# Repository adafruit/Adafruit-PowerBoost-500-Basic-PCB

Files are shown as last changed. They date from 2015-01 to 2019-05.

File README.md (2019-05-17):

## Adafruit PowerBoost 500 Basic PCB
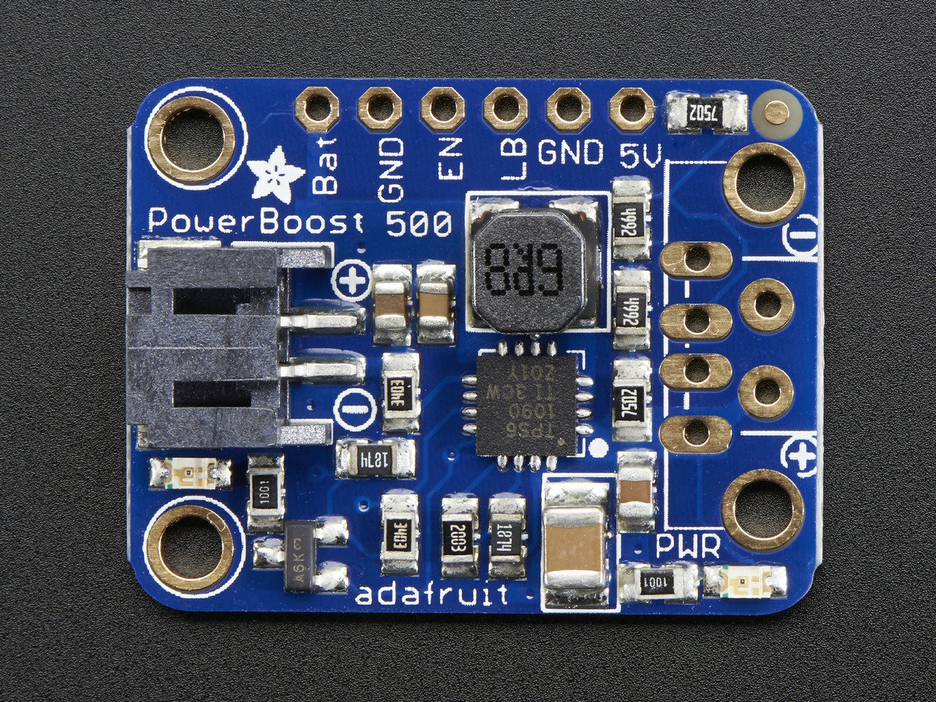
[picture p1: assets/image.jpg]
<a href="http://www.adafruit.com/products/1903"><br/>
Click here to purchase one from the Adafruit shop</a>

This little DC/DC boost converter module can run from 1.8V batteries or higher, and convert that voltage to 5.2V DC for running your 5V projects. Like our popular 5V 1A USB wall adapter, we tweaked the output to be 5.2V instead of a straight-up 5.0V so that there's a little bit of 'headroom' long cables, high draw, the addition of a diode on the output if you wish, etc. The 5.2V is safe for all 5V-powered electronics like Adafruit Metro/Trinket/Gemma/ItsyBitsy, Arduino, Raspberry Pi, or BeagleBone while preventing icky brown-outs during high current draw because of USB cable resistance.

The PowerBoost 500 has at the heart a TPS61090 boost converter from TI. This boost converter chip has some really nice extras such as low battery detection, 2A internal switch, synchronous conversion, excellent efficiency, and 700KHz high-frequency operation.

These are the Eagle CAD files for the Adafruit Adafruit PowerBoost 500 Basic breakout:
----> https://www.adafruit.com/product/1903

### License

Adafruit invests time and resources providing this open source design, please support Adafruit and open-source hardware by purchasing products from [Adafruit](https://www.adafruit.com)!

All text above must be included in any redistribution

Designed by Limor Fried/Ladyada for Adafruit Industries.
Creative Commons Attribution/Share-Alike, all text above must be included in any redistribution. 
See license.txt for additional information.

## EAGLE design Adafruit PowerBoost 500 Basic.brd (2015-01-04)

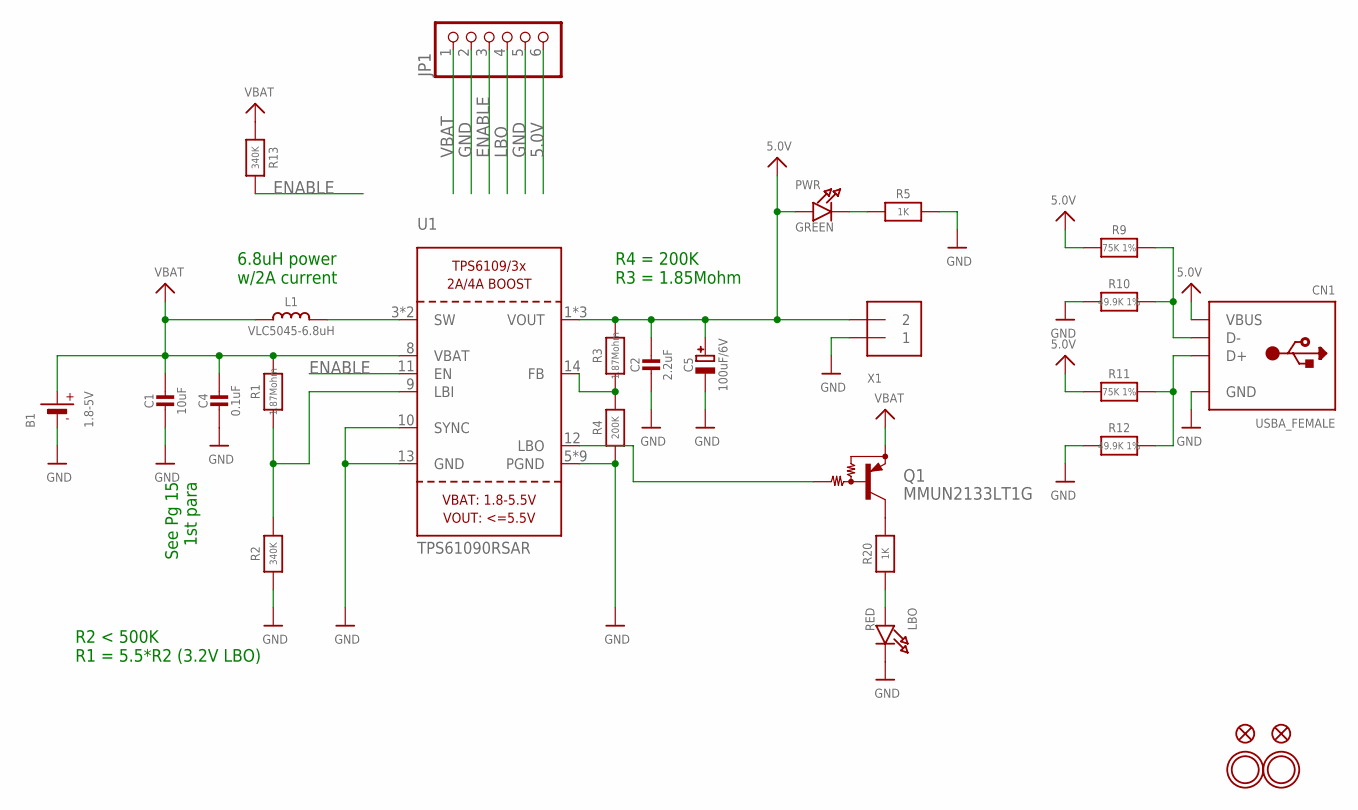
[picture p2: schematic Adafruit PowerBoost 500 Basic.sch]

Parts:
B1: 1.8-5V; JSTPH2
C1: 10uF; 0805-NO
C2: 2.2uF; 0805-NO
C4: 0.1uF; 0805-NO
C5: 100uF/6V; EIA3528-21/B-R
CN1: USBA_FEMALE; USB_HOST-PTH
FID2, FID3: FIDUCIAL""; FIDUCIAL_1MM
JP1: PINHD-1X6CB; 1X06-CLEANBIG
L1: VLC5045-6.8uH; INDUCTOR_5X5MM_TDK_VLC5045
LBO: RED; CHIPLED_0805_NOOUTLINE
PWR: GREEN; CHIPLED_0805_NOOUTLINE
Q1: MMUN2133LT1G; SC59-BEC
R1, R3: 1.87Mohm; 0805-NO
R2, R13: 340K; 0805-NO
R4: 200K; 0805-NO
R5, R20: 1K; 0805-NO
R9, R11: 75K 1%; 0805-NO
R10, R12: 49.9K 1%; 0805-NO
U1: TPS61090RSAR; PVQFN-16
U$10, U$12: MOUNTINGHOLE2.5; MOUNTINGHOLE_2.5_PLATED
X1: TERMBLOCK_1X2; TERMBLOCK_1X2-3.5MM

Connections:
5.0V: C2.1, C5.+, CN1.VBUS, JP1.6, PWR.A, R3.2, R9.2, R11.2, U1.1 (VOUT), U1.15 (VOUT), U1.16 (VOUT), X1.2
D+: CN1.D+, R11.1, R12.1
D-: CN1.D-, R9.1, R10.1
ENABLE: JP1.3, R13.2, U1.11 (EN)
GND: B1.1 (-), C1.2, C2.2, C4.2, C5.-, CN1.GND, JP1.2, JP1.5, LBO.C, R2.1, R4.1, R5.2, R10.2, R12.2, U1.5 (PGND), U1.6 (PGND), U1.7 (PGND), U1.10 (SYNC), U1.13 (GND), U1.P$18 (PGND), U1.P$19 (PGND), U1.P$20 (PGND), U1.P$21 (PGND), U1.P$22 (PGND), U1.THERMAL (PGND), X1.1
LBO: JP1.4, Q1.B, U1.12 (LBO)
unnamed: L1.P$2 (2), U1.3 (SW), U1.4 (SW)
unnamed: LBO.A, R20.1
unnamed: R1.1, R2.2, U1.9 (LBI)
unnamed: PWR.C, R5.1
unnamed: R3.1, R4.2, U1.14 (FB)
unnamed: Q1.C, R20.2
VBAT: B1.2 (+), C1.1, C4.1, JP1.1, L1.P$1 (1), Q1.E, R1.2, R13.1, U1.8 (VBAT)

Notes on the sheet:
See Pg 15 1st para
6.8uH power w/2A current
R2 < 500K R1 = 5.5*R2 (3.2V LBO)
R4 = 200K R3 = 1.85Mohm

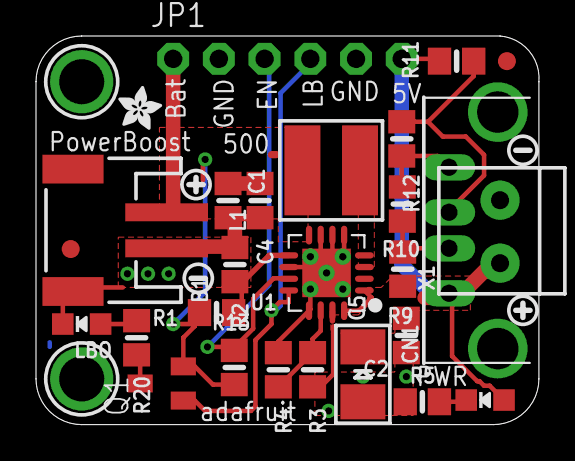
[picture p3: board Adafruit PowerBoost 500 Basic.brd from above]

Board: 2 copper layers, 27.9 x 21.6 mm, 34 parts (1 on the bottom side), 13 nets.

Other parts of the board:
U$13, U$25: SYMBOL_PLUS
U$23, U$26: SYMBOL_MINUS
U$28: ADAFRUIT_2.5MM
U$29: ADAFRUIT_5MM

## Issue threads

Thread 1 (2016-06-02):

When I try to open https://github.com/adafruit/Adafruit-PowerBoost-500-Basic-PCB sch file with Eagle 7.6, I get an error on line 6, column 56 that this is not an Eagle file.  What should I try next?

txpostman, 2016-06-02:

ladyada, 2016-06-02:
try eagle 6? the file is not bad, you'll need to figure out what you did wrong :)

txpostman, 2016-06-02:
> No description provided.

d it out.  I tried to download from the screen where the files are visible but I needed to download the zip file.  SCH and BRD files are not valid unless the zip or clone is used.  Thanks

Closed 2016-06-02.

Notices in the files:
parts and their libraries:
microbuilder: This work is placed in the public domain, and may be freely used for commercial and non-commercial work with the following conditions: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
